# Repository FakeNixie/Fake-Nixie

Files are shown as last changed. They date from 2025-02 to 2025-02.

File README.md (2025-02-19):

# Fake-Nixie
Fake Nixie erlojuak bost pantaila erabiltzen ditu ordua modu paregabean erakusteko Nixie balbula tradizionalak erabili ordez. Horietako bi pantailek ordua adierazten dute, beste bi pantailek minutuak, eta pantaila gehigarri batek bisualki bereizten ditu orduak eta minutuak 2 puntu karakteristikoak erakutsiz, efektu bisual erakargarri bat sortuz.

# Eskertzak

Hau guztia lortzeko hainbat lekutatik atera dugu informazioa, baino gehien bat Owenderew-k egindako github-etik atera dugu:

Owendrew github-a  https://github.com/owendrew/fakeNixie/blob/main/README.md

ESP32ak eta pantailak imagenak erakusteko irudi konbertidorea: https://marlinfw.org/tools/rgb565/converter.html

# Materiala

- [ESP32](https://www.amazon.es/AZDelivery-NodeMCU-ESP-WROOM-32-Tablero-Desarrollo/dp/B071P98VTG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) (unitate 1)

- ["ST7789 1.14 inch TFT LCD IPS"](https://www.amazon.es/Fiorky-135x240-Pantalla-pantalla-Interfaz/dp/B0D3C7NP6Z?th=1) (5 unitate)

- [2x4 pines macho de ángulo recto](https://www.amazon.es/LON0167-DC3-8PL-conector-Winkelstecker-IDC-Box-Header/dp/B09FF1Y3KF) (6 unitate)

- ["FPC FFC Cable 8 PIN 0.5mm pitch konektorea"](https://www.amazon.es/dp/B09XMF3QMP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) (5 unitate)

- [1x10 male header pins](https://es.farnell.com/wurth-elektronik/61301011121/macho-2-54-mm-pin-10-v-as/dp/1841229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) (4 unitate)

- [2x4 female header sockets (2,54mm pitch)](https://es.aliexpress.com/item/1005004372795403.html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,pvid:5058ee50-df86-4ca0-9f69-127fb1ced0d3,tpp_buckets:668%232846%238108%231977&pdp_npi=4%40dis%21EUR%210.82%210.82%21%21%210.88%210.88%21%40210318c317212735906453162efde5%21-1%21rec%21ES%21%21AB) (5 unitate)

- [Micro USB PSU kablea](https://tienda.bricogeek.com/cables/1471-cable-usb-micro-b-corto-85cm.html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) (unitate 1)

- [Pantailak tapatzeko kupulak](https://www.temu.com/es/kuiper/un9.html?goods_id=601099634148124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) (5 unitate)

- [Portapilas 2 AA](https://es.rs-online.com/web/p/portapilas/1854604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)  (2 unitate)

# [Pantailen Muntaketa](https://github.com/FakeNixie/Fake-Nixie/tree/main/Dokumentazioa/Eskemak)



Hasteko, patailak konektatzen hasi ginen nola funtzionatzen zuten jakiteko. Goian ikusi dezakezue guk egindako eskema, bertan nola konektatu eta ze pinetara eraman genituen pantailen kable bakoitza erakusten da. Eskema hori guk egin genuen ez genuelako datasheet argirik aurkitu.

# [Konexio Eskema](https://github.com/FakeNixie/Fake-Nixie/tree/main/Dokumentazioa/Eskemak)



Goiko irudian ikusi dezakezue guk egindako konexio eskema. Bertan, ESP32-ra nola konektatu ditugun pantailak ikusi dezakezue. 5 pantailen konexio guztiak pin berdinetara doaz 8. pina ezik. Pin honek, informazioa eramaten du, hau da, pantaiak rekusten duen irudi bakoitzak behar duen informazioa pin horretatik sartuko da. Konexio guztiak irudikatzeko eta eskema egiteko Proteus programa erabili dugu.

# [PCB Diseinua](https://github.com/FakeNixie/Fake-Nixie/tree/main/Dokumentazioa/PCB_Artxiboak)

 

Hurrengo urratsa, eskemaren pcb-a egitea izan zen. PCB-a egin genuen ez kablerik erabiltzeko eta dena modu ordenatu batean gelditzeko, horrela interferentziak saiestuko genituen eta konexio arazoak ekidituko genituen. Hau egiteko ere Proteus programa erabili dugu.

# [Kodea](https://github.com/FakeNixie/Fake-Nixie/tree/main/Dokumentazioa/Arduino)


Gure kodeak hasiera batean ordua erakusten zuen bakarrik eta ondoren diseinu ezberdinak gehitu dizkiogu. Konektatutako wifiaren bidez, gauden ordu-eremuko ordua hartzen du eta pantailetan erakusten du. Gainera, ordua WiFi bidez hartzen duenez erlojua beti eguneratuta egongo da. Gero, aplikazioa baten bitartez bi estilo ezberdin ditugu sartuta kodigoan eta aplikazioaren bidez kodigoan sortutako web orrialdera sartu eta estiloz aldatu dezakezu.

# Elikadura



Muntaiarekin bukatzeko, elikadura gehitu genien, gure proiektua ez egoteko ordenagailura konektatuta donbora guztian. Hau lortzeko bi portapilas hartu genituen eta 4 pilako portapilas batean bihurtu genuen. Honek 6V-ko tentsioa ematen dio ESP32 kontrolagailuari eta piztuta egon daiteke edozien tokitan ordenagailura konektatuta eduki gabe.
# [Aplikazioa](https://sites.google.com/d/18WV8YJMY_IQXxaLhMr7m3VHMnpldd2XD/p/1QMYbZgTesbHUEUoDU0BAqGxNVekRPJkL/edit)


Bukatzeko, Site formatuko aplikazio bat egin dugu. Honekin erlojua konfiguratzeko modu erraz bat eskeintzen dugu, web-era bideratzen diguna. Aplikazio honekin, ordua ikusi dezakegu eta estiloz aldatu deazkegu erlojua gure gustura gelditzeko.

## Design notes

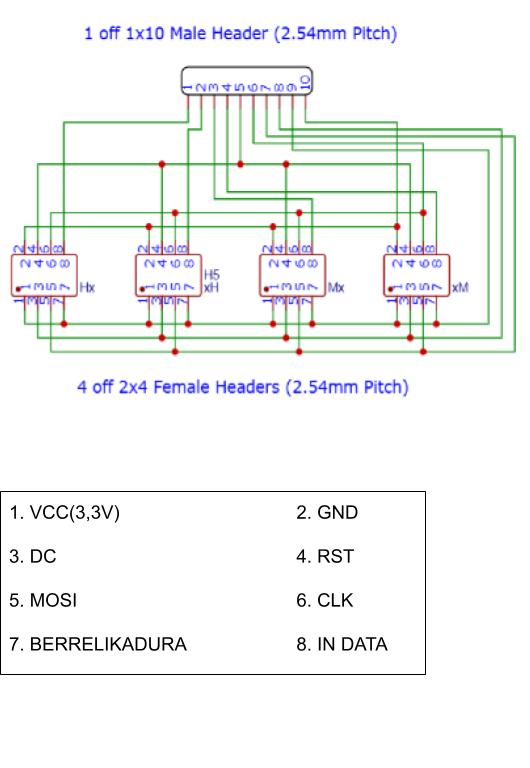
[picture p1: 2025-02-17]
Dokumentazioa/Eskemak/Pantaillaren Konexioak (1).jpg

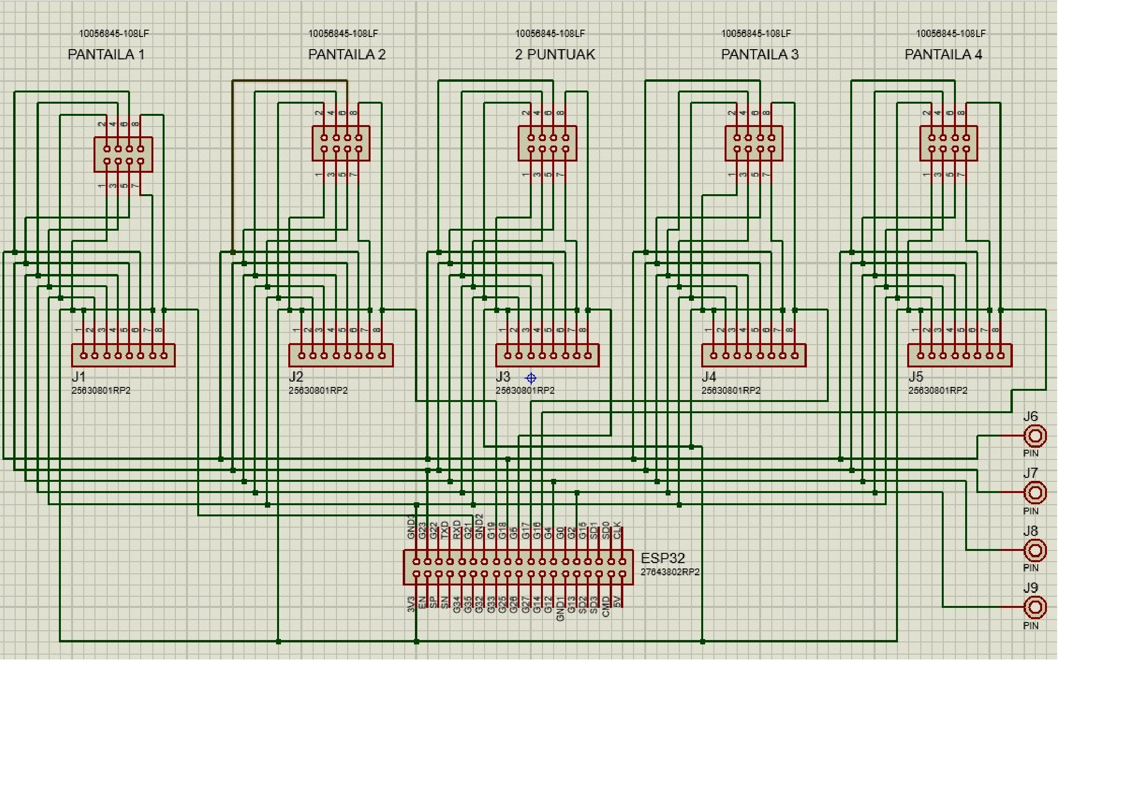
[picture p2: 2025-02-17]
Dokumentazioa/Eskemak/Esquema_Pantaillak.jpg

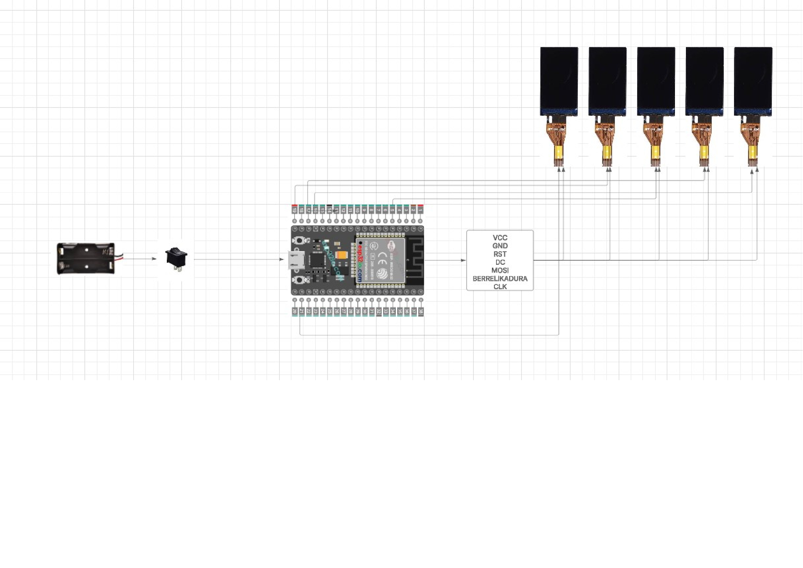
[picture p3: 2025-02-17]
Dokumentazioa/Eskemak/Konexio_esquema.jpg

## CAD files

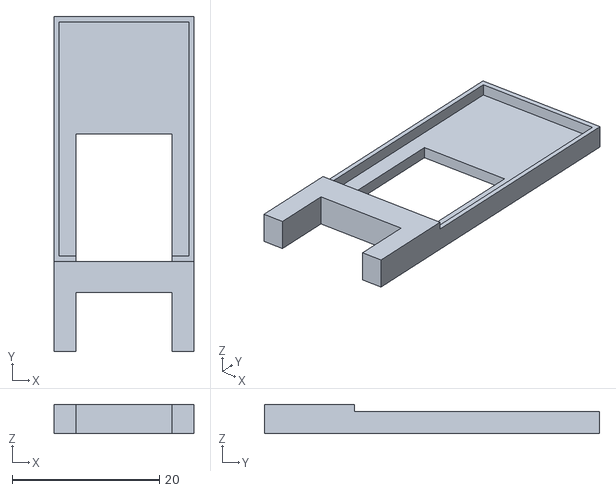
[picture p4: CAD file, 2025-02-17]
Dokumentazioa/3D_Piezak/Pantaillak.stl
19.0 x 45.5 x 4.00

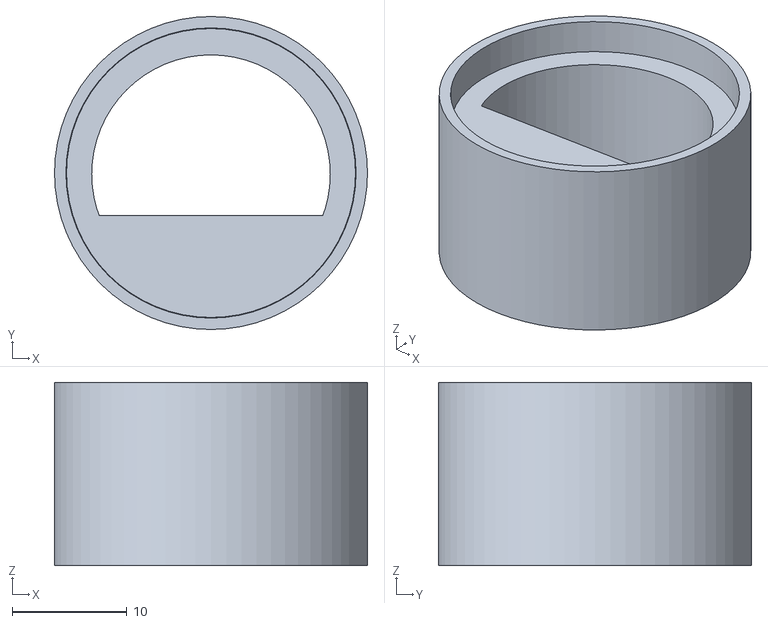
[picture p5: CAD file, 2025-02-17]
Dokumentazioa/3D_Piezak/Pantaillaren_Basea.stl
27.3 x 27.3 x 16.0

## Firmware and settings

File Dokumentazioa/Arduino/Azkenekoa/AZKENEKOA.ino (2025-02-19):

//====================================================================================
//                                  WIFI
//====================================================================================


//====================================================================================
//                                  DEFINIZOAK
//====================================================================================

#include <WiFi.h>
#include <WebServer.h>
#include <SPI.h>
#include "TFT_eSPI.h"
#include <time.h>
#include <Preferences.h>  //  NVS memoria godetrzeko libreria (memoria persistente)

#define digit1 21  // 1xxx Digit Enable Active Low
#define digit2 19  // x2xx Digit Enable Active Low
#define digit3 17  // xx3x Digit Enable Active Low
#define digit4 16  // xxx4 Digit Enable Active Low
#define digit5 5   // irudi finkorako pantaila (bi puntuak)

#define PIN_HIGH true
#define PIN_LOW false

int BOTON = 33;

//====================================================================================
//                                  DIGITOEN DATA
//====================================================================================

#include "nixieFont.h"  // estilo 1
#include "nenonFont.h"  // estilo 2
#include "imagenFija.h" // irduiak (imagenFija y Nns)
  
//====================================================================================
//                                  LIBRERIAK
//====================================================================================
#include <SPI.h>               // Beharrezkoa TFT_eSPI (Displays)
#include "TFT_eSPI.h"          // ESP32rako libreria espezifikoa.
#include "nixieClockConfig.h"  // Artxiboa zure WIFI kredentzialekin.
#include <time.h>              // Denbora funtzio libreria
#include <WiFi.h>              // WiFi libreria

//====================================================================================
//                                    BARIABLEAK ETA KONSTANTEAK
//====================================================================================
//KONEXIO KREDENTZIALAK
//const char* ssid = "ETT IKASLEAK";
//const char* password = "1Kasl3@na1z";
const char* dstRule = "CET-1CEST,M3.5.0,M10.5.0/3";  // Ordu zona gordetzeko kodea -> nixieClockConfig.h
//
int minutesUnits, minutesTens, hoursUnits, hoursTens, nmins, nhour;
int oldMinuteUnits = 99, oldMinutesTens = 99, oldHoursUnits = 99, oldHoursTens = 99;
time_t currentTime;
bool pulsado = false;
bool estiloNixie = true;  // True = Nixie, False = Nenon
bool mostrarImagenFija = true;  // imagenFija edo Nns erakusten duen kontrolatzen du

unsigned long currentMillis;
unsigned long lastUpdateTime;
unsigned long updateInterval = 30000;  // 30s ekibalentea

//  "nixieFont.h" daude definitututa digitoak
static const unsigned short* nixieNumeral[] = { Nx0, Nx1, Nx2, Nx3, Nx4, Nx5, Nx6, Nx7, Nx8, Nx9,};
static const unsigned short* nenonNumeral[] = { Nn0, Nn1, Nn2, Nn3, Nn4, Nn5, Nn6, Nn7, Nn8, Nn9,};

//====================================================================================
//                                   WIFI BARIABLEAK
//====================================================================================
const char* apSSID = "FAKE NIXIE";
const char* apPassword = "12345678";

char wifiSSID[32] = "";
char wifiPassword[32] = "";
bool credentialsReceived = false;

WebServer server(80);
TFT_eSPI tft = TFT_eSPI();
Preferences preferences; // Manejo de memoria persistente

//====================================================================================
//                                   WEB INTERFAZA
//====================================================================================
void startWebInterface() {
    if (WiFi.status() == WL_CONNECTED) {
        Serial.println("Iniciando interfaz web para configuración...");

        // Defektuzko ruta"/" → Redirige a "/config"
        server.on("/datetime", HTTP_GET, []() {
          server.send(200, "text/plain", obtenerFechaHora());
        });


        //Erlojua konfiguratzeko orria, estiloa aldatzeko botoiarekin
        server.on("/config", HTTP_GET, []() {
          String html = R"rawliteral(
              <!DOCTYPE html>
              <html lang="en">
              <head>
                  <meta charset="UTF-8">
                  <meta name="viewport" content="width=device-width, initial-scale=1.0">
                  <title>Fake Nixie Clock</title>
                  <style>
                      body {
                          background-color: #111;
                          color: #ff9800;
                          font-family: 'Courier New', Courier, monospace;
                          text-align: center;
                          padding: 20px;
                      }
                      h1 {
                          font-size: 3em;
                          margin-bottom: 10px;
                      }
                      .date {
                          font-size: 2em;
                          font-weight: bold;
                          margin-bottom: 10px;
                      }
                      .clock {
                          font-size: 4em;
                          font-weight: bold;
                          letter-spacing: 10px;
                          text-shadow: 0 0 10px #ff6d00, 0 0 20px #ff9800, 0 0 30px #ff3d00;
                      }
                      .container {
                          display: flex;
                          flex-direction: column;
                          align-items: center;
                          justify-content: center;
                          height: 70vh;
                      }
                      button {
                          background-color: #ff6d00;
                          border: none;
                          color: white;
                          padding: 15px 30px;
                          font-size: 1.2em;
                          cursor: pointer;
                          margin-top: 20px;
                          border-radius: 8px;
                          text-transform: uppercase;
                          transition: all 0.3s ease;
                      }
                      button:hover {
                          background-color: #ff3d00;
                          transform: scale(1.1);
                      }
                  </style>
              </head>
              <body>
                  <h1>FAKE NIXIE</h1>
                  <div class="container">
                      <div id="date" class="date">Loading date...</div> <!-- Aquí se mostrará la fecha -->
                      <div id="clock" class="clock">Loading time...</div> <!-- Aquí se mostrará la hora -->
                      <form action="/cambiar_estilo" method="POST">
                          <button type="submit">Change Style</button>
                      </form>
                  </div>
                  <script>
                      function actualizarFechaHora() {
                          fetch('/datetime')  // Solicita la fecha y hora al ESP32
                          .then(response => response.text())
                          .then(data => {
                              let partes = data.split('|');  // Divide la respuesta en fecha y hora
                              document.getElementById('date').innerText = partes[0]; // Fecha
                              document.getElementById('clock').innerText = partes[1]; // Hora
                          })
                          .catch(error => console.log("Error obteniendo la fecha y hora:", error));
                      }
                      setInterval(actualizarFechaHora, 1000);  // Actualizar cada segundo
                      actualizarFechaHora();  // Llamar al inicio
                  </script>
              </body>
              </html>
          )rawliteral";

          server.send(200, "text/html", html);
      });



        // Ordu zona gordetzeko
        server.on("/update", HTTP_POST, []() {
            if (server.hasArg("timezone")) {
                String newTimezone = server.arg("timezone");

                // Memoria gorde NVS
                preferences.begin("settings", false);
                preferences.putString("timezone", newTimezone);
                preferences.end();

                // Aldaketa aplikatzeko
                setTimezone(newTimezone);

                server.send(200, "text/html", "<h2>Zona horaria actualizada.</h2><a href='/config'>Volver</a>");
            } else {
                server.send(400, "text/plain", "Faltan parámetros.");
            }
        });

        // Erlojuaren estiloa aldatzeko botoia
        server.on("/cambiar_estilo", HTTP_POST, []() {
            Cambio_de_estilo();  // Llama a la función para alternar el estilo
            server.send(200, "text/html", "<h2>Estilo cambiado.</h2><a href='/config'>Volver</a>");
        });

        server.begin();
    }
}
//====================================================================================
//                            WIFI && ACCESS POINT FUNTZIOAK
//====================================================================================

void startAccessPoint() {
    WiFi.softAP(apSSID, apPassword);
    Serial.println("Access Point Started");
    Serial.print("IP Address: ");
    Serial.println(WiFi.softAPIP());

    server.on("/", HTTP_GET, []() {
        server.send(200, "text/html", "<html><body><h2>WiFi Configuration</h2><form action='/connect' method='POST'>"
                    "SSID: <input type='text' name='ssid'><br>"
                    "Password: <input type='password' name='password'><br>"
                    "<input type='submit' value='Connect'></form></body></html>");
    });

    server.on("/connect", HTTP_POST, []() {
    if (server.hasArg("ssid") && server.hasArg("password")) {
        strcpy(wifiSSID, server.arg("ssid").c_str());
        strcpy(wifiPassword, server.arg("password").c_str());
        credentialsReceived = true;
        
        //  NVS irekitzen dugu idazketa moduan 
        preferences.begin("wifi", false);
        preferences.putString("ssid", String(wifiSSID));  // Guardamos el SSID
        preferences.putString("password", String(wifiPassword));  // Guardamos la contraseña
        preferences.end();  // NVS itxitzen dugu modu egokian
        
        Serial.println("Credenciales guardadas en memoria NVS");
        server.send(200, "text/plain", "Received, attempting connection...");
    } else {
        server.send(400, "text/plain", "Missing arguments");
    }
});

    server.begin();
}

  void connectToWiFi() {
      Serial.print("Connecting to WiFi: ");
      Serial.println(wifiSSID);

      WiFi.begin(wifiSSID, wifiPassword);
      int attempts = 0;
      while (WiFi.status() != WL_CONNECTED && attempts < 20) {
          delay(500);
          Serial.print(".");
          attempts++;
      }
      
      if (WiFi.status() == WL_CONNECTED) {
          String newIP = WiFi.localIP().toString();
          Serial.println("\nConnected!");
          Serial.print("IP Address: ");
          Serial.println(newIP);

          // 🔹 Mostrar la IP en la pantalla por unos segundos
          mostrarIPenPantalla(newIP);
      } else {
          Serial.println("Failed to connect");
      }
  }


//====================================================================================
//                                    setup
//====================================================================================
void setup() {
    Serial.begin(115200);
    delay(100);

    pinMode(digit1, OUTPUT);
    pinMode(digit2, OUTPUT);
    pinMode(digit3, OUTPUT);
    pinMode(digit4, OUTPUT);
    pinMode(digit5, OUTPUT);  // Irudi finkorako 5. pantaila (2 puntuak)
    pinMode(BOTON, INPUT);

    // Pantaila nagusia abiaraztea (erlojuarentzat)
    enableDisplays();
    tft.begin();
    tft.setRotation(0);         // 0 & 2 Portrait. 1 & 3 landscape
    tft.fillScreen(TFT_BLACK);  // Pantailak garbitu (Beltzaratu)
    tft.setSwapBytes(true);     // Requred for the 1.14" IPS SPI (8pin) LCD displays from Aliexpress
    tft.setCursor(0, 0, 2);
    tft.setTextColor(TFT_WHITE);
    tft.setTextFont(1);
    tft.setTextFont(2);
    
    // Gordetako WiFi kredentzialak irakurtzeko
    preferences.begin("wifi", true);  //  Irakuketa modua soilik
    String storedSSID = preferences.getString("ssid", "");
    String storedPassword = preferences.getString("password", "");
    preferences.end();  //  Memoria itxi irakurri ondoren 

    if (storedSSID.length() > 0) {  // Kredentzialak gordeta badaude...
        strcpy(wifiSSID, storedSSID.c_str());
        strcpy(wifiPassword, storedPassword.c_str());
        Serial.println("Conectando a WiFi guardado: " + storedSSID);
        connectToWiFi();
        
        // 10 segundotan konektatzea lortzen ez badu, aktibatu AP
        unsigned long startAttemptTime = millis();
        while (WiFi.status() != WL_CONNECTED && millis() - startAttemptTime < 10000) {
            delay(500);
            Serial.print(".");
        }

        if (WiFi.status() == WL_CONNECTED) {
            Serial.println("Conectado a WiFi correctamente.");
        } else {
            Serial.println("No se pudo conectar. Activando AP...");
            startAccessPoint();
        }
    } else {
        Serial.println("No se encontraron credenciales guardadas, activando AP...");
        startAccessPoint();  // Ez badago daturik gordeta, aktibatu AP modua
    }

    // 🔹 Irakurri estiloaren konfigurazioa eta ordu-eremua
    preferences.begin("settings", true);  // Irakuketa modua soilik
    String storedEstilo = preferences.getString("estilo", "nixie");
    String storedTimezone = preferences.getString("timezone", "CET-1CEST,M3.5.0,M10.5.0/3");
    preferences.end();

    // Gordetako balioak aplikatzea
    estiloNixie = (storedEstilo == "nixie");
    setTimezone(storedTimezone);
    
    // 🔹 Hasi web interfazea WiFi konektatuta badago
    if (WiFi.status() == WL_CONNECTED) {
        startWebInterface();
    }

    disableDisplays();  // 1-4 pantailak lehenetsita desabilitatu
    initTime(dstRule);  // Londreseko ordu-eremua gorde eta aplikatu (Set timezone and daylight saving for London)?
    lastUpdateTime = millis();
    mostrarImagen();// Hasierako irudi finkoa erakutsi bosgarren pantailan
}

//====================================================================================
//                                 VOID LOOP
//====================================================================================
void loop() {
  server.handleClient(); //WIFI
    if (credentialsReceived) {
        WiFi.softAPdisconnect(true);
        connectToWiFi();
        credentialsReceived = false;
    }

  currentMillis = millis();

  if (digitalRead(BOTON) == LOW) {
    pulsado = true;
  }
  if (digitalRead(BOTON) == HIGH && pulsado == true) {
    pulsado = false;
    Cambio_de_estilo();  //Erloju-estiloa eta irudi finkoa aldatzea
  }

  // Ordua eguneratzea, dagoen kodearen arabera
  if (currentMillis - lastUpdateTime >= updateInterval) {
    lastUpdateTime = currentMillis;
    initTime(dstRule);  //Eguneratu ordua NTP zerbitzaritik
  }

  timeVariablesSet();  // Funtzio honek nsecs, nmins, nhour aldagaiak ezartzen ditu.

  minutesUnits = nmins % 10;        //atera minutu kopuruaren digitu unitarioan mins
  minutesTens = (nmins / 10) % 10;  // atera minutu kopuruaren digitu unitarioa nmins
  hoursUnits = nhour % 10;          // atera ordu kopuruaren digitu unitarioa nhour
  hoursTens = (nhour / 10) % 10;    // atera ordu kopuruaren digitu unitarioa nhour

  if (oldMinuteUnits != minutesUnits) {
    loadDigit(digit4, minutesUnits);  // Kargatu Digitua erakusteko
    oldMinuteUnits = minutesUnits;
  }

  if (oldMinutesTens != minutesTens) {
    loadDigit(digit3, minutesTens);  // Kargatu Digitua erakusteko
    oldMinutesTens = minutesTens;
  }

  if (oldHoursUnits != hoursUnits) {
    loadDigit(digit2, hoursUnits);  // Kargatu Digitua erakusteko
    oldHoursUnits = hoursUnits;
  }

  if (oldHoursTens != hoursTens) {
    loadDigit(digit1, hoursTens);  // Kargatu Digitua erakusteko
    oldHoursTens = hoursTens;
  }
}

//====================================================================================
//                                 initTime
//====================================================================================
void initTime(String timezone) {
  struct tm timeinfo;
  Serial.println("Setting up time");
  configTime(0, 0, "pool.ntp.org");  // Lehenengo konektatu NTP zerbitzariarekin, 0 TZ offset-ekin.
  if (!getLocalTime(&timeinfo)) {
    Serial.println("initTime: Failed to obtain time");
    return;
  }
  setTimezone(timezone);
}

//====================================================================================
//                                 timeVariablesSet
//====================================================================================
void timeVariablesSet() {
  struct tm timeinfo;
  if (!getLocalTime(&timeinfo)) {
    Serial.println("timeVariableSet: Failed to obtain time");
    return;
  }

  nmins = (timeinfo.tm_min);
  nhour = (timeinfo.tm_hour);
}

//====================================================================================
//                                 Set Time Zone
//====================================================================================
void setTimezone(String timezone) {
  setenv("TZ", timezone.c_str(), 1);  // Egokitu TZ. Erlojuaren konfigurazioa egokitu egin da toki berria erakusteko.
  tzset();
}

//====================================================================================
//                                 Display digit on LCD x
//====================================================================================
void loadDigit(int displayPin, int numeral) {
  digitalWrite(displayPin, PIN_LOW);  // Pantaila eguneratzeko aukera ematen du.
  if (estiloNixie) {
    tft.pushImage(0, 0, 135, 240, nixieNumeral[numeral]);  //Erakutsi irudi zuzena
  } else {
    tft.pushImage(0, 0, 135, 240, nenonNumeral[numeral]);  // Erakutsi irudi zuzena
  }
  digitalWrite(displayPin, PIN_HIGH);  // Eguneratu ondoren, pantaila desaktibatu.
}

//====================================================================================
//                                 BOSTGARREN PANTAILAN IRUDIA ERAKUTSI
//====================================================================================
void mostrarImagen() {
  digitalWrite(digit5, PIN_LOW);  // Bosgarren pantaila gaitu
  if (mostrarImagenFija) {
    tft.pushImage(0, 0, 135, 240, imagenFija);  // Erakutsi imagenFija
  } else {
    tft.pushImage(0, 0, 135, 240, Nns);  // Erakutsi Nns
  }
  digitalWrite(digit5, PIN_HIGH);  // Bosgarren pantaila desgaitu
}

//====================================================================================
//                                 ESTILOA ALDATU
//====================================================================================
void Cambio_de_estilo() {
  estiloNixie = !estiloNixie;  // Nixie eta Nenon artean alternatu
  mostrarImagenFija = !mostrarImagenFija;  //  imagenFija eta  Nns artean alternatu

  // 1-4 pantailetan erlojua eguneratzea
  loadDigit(digit1, hoursTens);
  loadDigit(digit2, hoursUnits);
  loadDigit(digit3, minutesTens);
  loadDigit(digit4, minutesUnits);

  // Eguneratu irudia bosgarren pantailan
  mostrarImagen();
}

//====================================================================================
//                                 Enable all displays
//====================================================================================
void enableDisplays() {
  digitalWrite(digit1, PIN_LOW);
  digitalWrite(digit2, PIN_LOW);
  digitalWrite(digit3, PIN_LOW);
  digitalWrite(digit4, PIN_LOW);
}

//====================================================================================
//                                 Disable all displays
//====================================================================================
void disableDisplays() {
  digitalWrite(digit1, PIN_HIGH);  // Pantaila guztiak desabilitatu
  digitalWrite(digit2, PIN_HIGH);
  digitalWrite(digit3, PIN_HIGH);
  digitalWrite(digit4, PIN_HIGH);
}

//====================================================================================
//                                 Obtener fecha y hora
//====================================================================================
String obtenerFechaHora() {
    struct tm timeinfo;
    if (!getLocalTime(&timeinfo)) {
        Serial.println("Error obteniendo la fecha y hora");
        return "Error";
    }
    char fecha[30];
    char hora[10];
    // Formatear la fecha en inglés
    strftime(fecha, sizeof(fecha), "%A, %d %B %Y", &timeinfo); // Ej: "Wednesday, 12 February 2025"
    // Formatear la hora en formato 24h
    strftime(hora, sizeof(hora), "%H:%M:%S", &timeinfo); // Ej: "14:45:30"
    // Crear la cadena completa con separador '|'
    return String(fecha) + "|" + String(hora);
}

//====================================================================================
//                            Mostrar IP en pantalla
//====================================================================================
void mostrarIPenPantalla(String ip) {
    digitalWrite(digit5, PIN_LOW);  // Activar la pantalla para mostrar la IP
    tft.fillScreen(TFT_BLACK);      // Limpiar la pantalla
    tft.setTextColor(TFT_WHITE, TFT_BLACK);
    tft.setTextSize(2);
    tft.setCursor(10, 50);          // Ajustar posición del texto
    tft.print("IP:");
    tft.setCursor(10, 80);
    tft.print(ip);                  // Mostrar la IP en pantalla
    delay(5000);                     // Mantener la IP visible por 5 segundos
    digitalWrite(digit5, PIN_HIGH);  // Apagar la pantalla después del tiempo
}

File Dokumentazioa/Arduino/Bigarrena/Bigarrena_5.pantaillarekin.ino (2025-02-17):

//====================================================================================
//                                  Definitions
//====================================================================================

#define digit1 21  // 1xxx Digit Enable Active Low
#define digit2 22  // x2xx Digit Enable Active Low
#define digit3 17  // xx3x Digit Enable Active Low
#define digit4 16  // xxx4 Digit Enable Active Low
#define digit5 5   // Quinta pantalla para la imagen fija

#define PIN_HIGH true
#define PIN_LOW false

int BOTON = 33;

//====================================================================================
//                                  Digit data includes
//====================================================================================

#include "nixieFont.h"  // Fuente 1
#include "nenonFont.h"  // Fuente 2
#include "imagenFija.h" // Imágenes (imagenFija y Nns)

//====================================================================================
//                                  Libraries
//====================================================================================
#include <SPI.h>               // required for TFT_eSPI (Displays)
#include "TFT_eSPI.h"          // Hardware-specific library for ESP32
#include "nixieClockConfig.h"  // The file with your WIFI credentials
#include <time.h>              // time library functions
#include <WiFi.h>              // WiFi library

//====================================================================================
//                                    Variables and Constants
//====================================================================================
const char* ssid = "ETT IKASLEAK";
const char* password = "1Kasl3@na1z";
const char* dstRule = "CET-1CEST,M3.5.0,M10.5.0/3";  // daylight saving code from nixieClockConfig.h

int minutesUnits, minutesTens, hoursUnits, hoursTens, nmins, nhour;
int oldMinuteUnits = 99, oldMinutesTens = 99, oldHoursUnits = 99, oldHoursTens = 99;
time_t currentTime;
bool pulsado = false;
bool estiloNixie = true;  // True = Nixie, False = Nenon
bool mostrarImagenFija = true;  // Controla si se muestra imagenFija o Nns

unsigned long currentMillis;
unsigned long lastUpdateTime;
unsigned long updateInterval = 30000;  // this equates to 30 secs

// Digit are defined in "nixieFont.h"
static const unsigned short* nixieNumeral[] = {
  Nx0,
  Nx1,
  Nx2,
  Nx3,
  Nx4,
  Nx5,
  Nx6,
  Nx7,
  Nx8,
  Nx9,
};
static const unsigned short* nenonNumeral[] = {
  Nn0,
  Nn1,
  Nn2,
  Nn3,
  Nn4,
  Nn5,
  Nn6,
  Nn7,
  Nn8,
  Nn9,
};

//====================================================================================
//                                    Initialise Functions
//====================================================================================
WiFiServer server(80);
TFT_eSPI tft = TFT_eSPI();  // Pantalla principal (para el reloj)

//====================================================================================
//                                    Setup
//====================================================================================
void setup() {
  Serial.begin(115200);  // Used for debug messages
  delay(100);

  Serial.println("Fake Nixie Clock");

  pinMode(digit1, OUTPUT);
  pinMode(digit2, OUTPUT);
  pinMode(digit3, OUTPUT);
  pinMode(digit4, OUTPUT);
  pinMode(digit5, OUTPUT);  // Quinta pantalla para la imagen fija
  pinMode(BOTON, INPUT);

  // Inicializar la pantalla principal (para el reloj)
  enableDisplays();
  tft.begin();
  tft.setRotation(0);         // 0 & 2 Portrait. 1 & 3 landscape
  tft.fillScreen(TFT_BLACK);  // Clear the screens
  tft.setSwapBytes(true);     // Requred for the 1.14" IPS SPI (8pin) LCD displays from Aliexpress
  tft.setCursor(0, 0, 2);
  tft.setTextColor(TFT_WHITE);
  tft.setTextFont(1);
  tft.println(F("Connecting to "));
  tft.setTextFont(2);
  tft.println(ssid);

  WiFi.setHostname("NIXIE_CLOCK");  // We start by connecting to a WiFi network
  WiFi.begin(ssid, password);
  while (WiFi.status() != WL_CONNECTED) {
    delay(500);
    tft.print(F("."));
  }
  tft.println("");
  tft.println(F("WiFi connected."));
  tft.println(F("IP address: "));
  tft.println(WiFi.localIP());

  disableDisplays();  // Deshabilitar las pantallas 1-4 por defecto

  initTime(dstRule);  // Set timezone and daylight saving for London

  lastUpdateTime = millis();

  // Mostrar la imagen fija inicial en la quinta pantalla
  mostrarImagen();
}

//====================================================================================
//                                    Loop
//====================================================================================
void loop() {
  currentMillis = millis();

  if (digitalRead(BOTON) == LOW) {
    pulsado = true;
  }
  if (digitalRead(BOTON) == HIGH && pulsado == true) {
    pulsado = false;
    Cambio_de_estilo();  // Cambiar el estilo de reloj y la imagen fija
  }

  // Actualización de hora, según el código existente
  if (currentMillis - lastUpdateTime >= updateInterval) {
    lastUpdateTime = currentMillis;
    initTime(dstRule);  // Actualizar hora desde el servidor NTP
  }

  timeVariablesSet();  // This function sets the nsecs, nmins, nhour variables from system time

  minutesUnits = nmins % 10;        // extract the unit digit of the number of minutes from nmins
  minutesTens = (nmins / 10) % 10;  // extract the tens digit of the number of minutes from nmins
  hoursUnits = nhour % 10;          // extract the unit digit of the number of hours from nhour
  hoursTens = (nhour / 10) % 10;    // extract the tens digit of the number of hours from nhour

  if (oldMinuteUnits != minutesUnits) {
    loadDigit(digit4, minutesUnits);  // Load Digit to display
    oldMinuteUnits = minutesUnits;
  }

  if (oldMinutesTens != minutesTens) {
    loadDigit(digit3, minutesTens);  // Load Digit to display
    oldMinutesTens = minutesTens;
  }

  if (oldHoursUnits != hoursUnits) {
    loadDigit(digit2, hoursUnits);  // Load Digit to display
    oldHoursUnits = hoursUnits;
  }

  if (oldHoursTens != hoursTens) {
    loadDigit(digit1, hoursTens);  // Load Digit to display
    oldHoursTens = hoursTens;
  }
}

//====================================================================================
//                                 initTime
//====================================================================================
void initTime(String timezone) {
  struct tm timeinfo;
  Serial.println("Setting up time");
  configTime(0, 0, "pool.ntp.org");  // First connect to NTP server, with 0 TZ offset
  if (!getLocalTime(&timeinfo)) {
    Serial.println("initTime: Failed to obtain time");
    return;
  }
  setTimezone(timezone);
}
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

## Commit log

2025-02-17 Create Arduino
2025-02-17 Rename 1.14_ TFT LCD Mount (Fake Nixie).stl to Pantaillak.stl
    [Pantaillak.stl]
2025-02-17 Rename Glass Mount (Fake Nixie).stl to Pantaillaren_Basea.stl
    [Pantaillaren_Basea.stl]
